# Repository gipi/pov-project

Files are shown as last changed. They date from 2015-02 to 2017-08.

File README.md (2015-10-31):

If you want to try this project you have to initialize using repo
the dependencies

```
$ mkdir pov && cd pov
$ repo init -u http://github.com/gipi/pov-project.git -b master
$ repo sync
```

Now you have some directory:

 - ``src`` containing the source code
 - ``build`` containing the library and build system for AVR

or you can download seperately the build system (my ``avr_stuffs`` repo)
and use the ``CORE_BUILD_DIR`` variable pointing to it

    $ make -C firmware/ CORE_BUILD_DIR=/path/to/build/system

## Test Accelerometer

    make -C firmware/ADXL345/ -f /opt/avr_stuffs/ciaoduino/Makefile.ciaoduino USER_LIB_PATH=~/Arduino/libraries/  ARDUINO_LIBS="Adafruit_Unified_Sensor Adafruit_ADXL345 Wire"

## Links

 - [Post](http://ao2.it/en/blog/2014/04/16/jmp-rope-theory-and-software) about a similar project
 - [Adafruit's related project](https://github.com/adafruit/Adafruit-MiniPOV4-Kit)
 - [Adafruit's very similar project](https://learn.adafruit.com/spokepov/)

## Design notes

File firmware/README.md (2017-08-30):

This directory contains the code to burn in this board as bootloader, it depends
on [LUFA](http://fourwalledcubicle.com/LUFA.php) version 140928.

In order to program with the bootloader you have to ``RESET`` the board while holding
the ``BOOT`` button.
After that the device will alternate on/off the first two leds of the board. 

## Bootloader

There is an extracted tree from the Sparfun's Atmega32u4 breakout (original repository
is [here](https://github.com/sparkfun/32U4_Breakout_Board/tree/master/Bootloaders)).

It's possible to build passing the path to the ``LUFA`` library path, like

    $ make LUFA_PATH=/opt/LUFA-140928/LUFA

(the command must be issued into the ``bootloader/CDC/`` directory). After
the ``hex`` file are generated you can upload with

    $ avrdude -c buspirate -p atmega32u4 -P /dev/ttyUSB0 -b 115200 -F -U flash:w:bootloaders/CDC/BootloaderCDC.hex

The bootloader is capable of emulating a ``avr109`` protocol and you can flash a file
with

    $ avrdude -c avr109 -p atmega32u4 -P /dev/ttyACM0 -F -U flash:w:path/to/file.hex

It's possible to use the arduino IDE with the following ``boards.txt`` entries

```
ciaoduino.name=CiaoDuino
ciaoduino.vid.0=0x2341
ciaoduino.pid.0=0x0036
ciaoduino.vid.1=0x2341
ciaoduino.pid.1=0x8036
ciaoduino.vid.2=0x2A03
ciaoduino.pid.2=0x0036
ciaoduino.vid.3=0x2A03
ciaoduino.pid.3=0x8036

ciaoduino.upload.tool=avrdude
ciaoduino.upload.protocol=avr109
ciaoduino.upload.maximum_size=28672
ciaoduino.upload.maximum_data_size=2560
ciaoduino.upload.speed=57600
ciaoduino.upload.disable_flushing=true
ciaoduino.upload.use_1200bps_touch=true
ciaoduino.upload.wait_for_upload_port=true

ciaoduino.build.mcu=atmega32u4
ciaoduino.build.f_cpu=16000000L
ciaoduino.build.vid=0x2341
ciaoduino.build.pid=0x8036
ciaoduino.build.usb_product="Arduino Leonardo"
ciaoduino.build.board=AVR_LEONARDO
ciaoduino.build.core=arduino
ciaoduino.build.variant=leonardo
ciaoduino.build.extra_flags={build.usb_flags}
```

(we don't know what is strictly necessary) to flash directly into this board. Probably
a manual ``RESET`` is necessary.

## Fuses

You have to set your fuse so that the ``HWBE`` is enabled but not ``BOOT RESET``
(we want the bootloader to be loaded only with the boot button).

A working fuses configuration is obtained with the following command

    $ avrdude -c buspirate -p atmega32u4 -P /dev/ttyUSB0 -b 115200 -U lfuse:w:0xce:m -U hfuse:w:0x99:m -U efuse:w:0xc3:m

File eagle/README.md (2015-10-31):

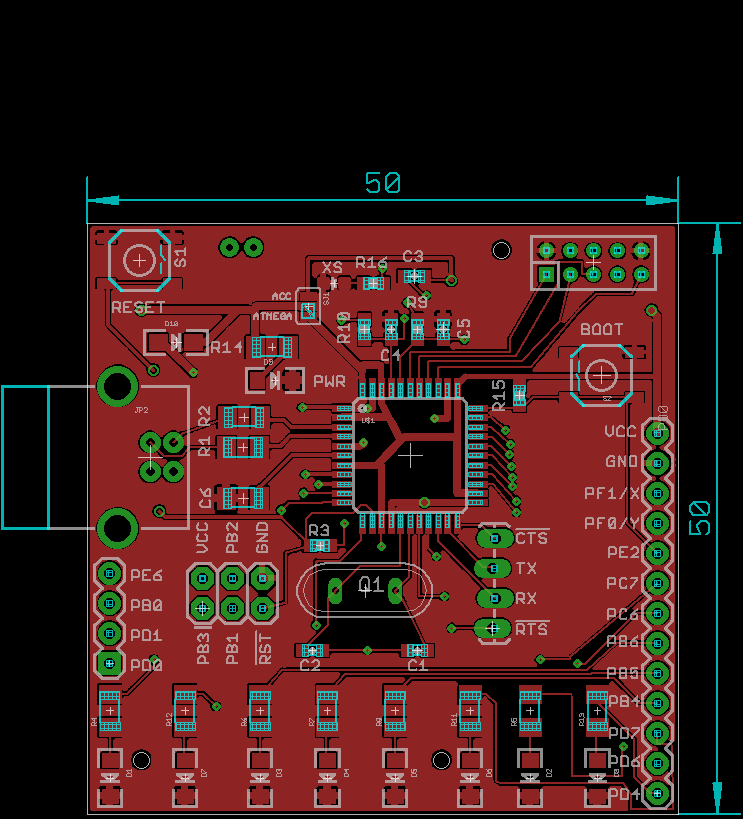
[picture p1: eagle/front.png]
top board layout

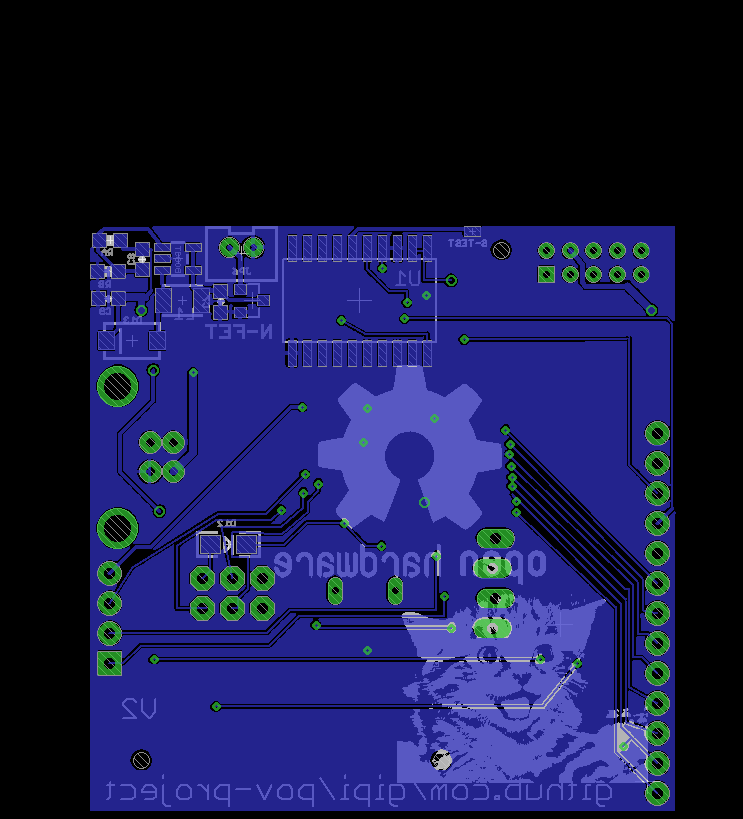
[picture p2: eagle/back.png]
bottom board layout


The ``SJ1`` is a solder-jump that decides which chips  must be powered: the central
pad is the power supply, the left pad is connected to the ``VCC`` of the ``ATMega32U4``
and the right one is connected to the ``VCC`` of the accelerometer. In this way is possible
to test separately these two ICs.

## TODO

 - move power-on led on the other side of the board so to not interfere with POV leds
 - add button to activate device
 - differentiate power supply between USB and battery (maybe use opamp like arduino boards do)
 - use less power consuming accelerometer (MPU-9255)
 - use sensor that gives absolute angular position
 - calculate energy consumption and minimize it
 - calculate theoretically operations timing (is it possible to read from ADC and displaying a picture reliably?)
 - expose pin for external generic power supply (connect them to the battery so we save some diodes)
 - separate pins for ``SPI``, ``I2C``, ``USART`` with power pins near for each of them in order to facilitate coupling with related devices
 - AVCC must be connected to VCC through a low-pass filter

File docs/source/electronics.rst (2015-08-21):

Electronics
===========

Microcontroller
---------------

We are using a ``ATMega32U4`` that has 16MHz clock and a timer with 8-bits resolution
and two available ADC channels with 10 bits resolution.

Accelerometer
-------------

In our solution we used the IC named ``MMA3202KEG``, that has two axis
with 100g and 50g of resolution. It's a linear accelerometer.

Soldering
---------

 #. ATmega32U4
 #. ICPS header
 #. the crystal and the related capacitors
 #. the diode connecyting ISP header with IC
 #. test the programmer sees the device
 #. reset button and reset resistor
 #. the passive part near the USB connector
 #. the USB connector
 #. solder the bridge to supply power to the IC
 #. test if the bootloader is accessible
 #. leds
 #. accelerometer

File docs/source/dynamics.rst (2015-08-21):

Dynamics
--------

Here we introduce the mathematics behind the calculation of the timing of the
led generated patterns: in order to calculate the timing we will using an
accelerometer; other systems(?) use a magnetic sensor to know the device
position and velocity but we don't like this solution since need to have a
magnet hanging on the bike itself.

Let :math:`\omega` be the angular velocity of the wheel, and :math:`R` the
external radius of the wheel and :math:`r` the distance from the center of
the wheel and the accelerometer, we have that the velocity of the wheel is given by

.. math::

   V = \omega R

using our test wheel at a velocity of
:math:`V = 18 km/h = {1.8\cdot 10^{4}\over 3600} m/s=5 m/s`
(using the average speed as indicated by `Wikipedia <https://en.wikipedia.org/wiki/Bicycle_performance#Typical_speeds>`_)
we obtain

.. math::

   \omega = {5 m/s\over 330\cdot 10^{-3}m} = 15.15 rad\cdot s^{-1} \qquad\hbox{i.e.}\quad
   f = {\omega\over 2\pi} = 2.41Hz

Since the centrifugal acceleration is

.. math::

   a = \omega^2\cdot r

we have that our test acceleration is

.. math::

   a = \left(15.15\cdot s^{-1}\right)^2\cdot 333\cdot 10^{-3} m = 76.43 m/s^2 \approx 8g

We need to know the angular velocity of the wheel in order to fit the timing
of the leds for the pattern to be displayed.

The accelerometer is moving together with the wheel and it's so placed in a not inertial
frame, experiencing a costant fictious acceleration along a fixed axes :math:`A` (we call the
axis :math:`A` and :math:`B` to avoid confusion with existing axis in the real device) and
a rotating acceleration with angular velocity :math:`\omega` and fixed magnitude :math:`g`.

When the accelerometer is at angle :math:`\theta` with respect to the vertical the
accelerations measured are

.. math::

    \begin{align}
    a_A &= a_0 + g\cdot\sin \theta\cr
    a_B &= g\cdot\cos\theta\cr
    \end{align}

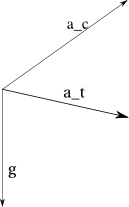
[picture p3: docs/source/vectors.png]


This allows us to calculate the accelerometer angular position from the second equation,
using it in the first to retrieve the angular acceleration and finally compute the angular
velocity (actually the angular position is determined knowning if also the slope of variation
of acceleration otherwise there are two solutions). 

An accelerometer will show reading like this

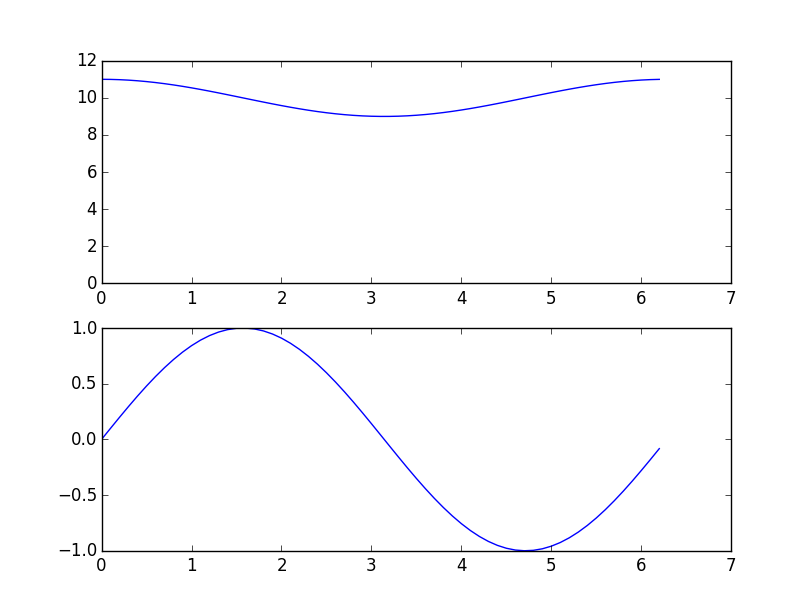
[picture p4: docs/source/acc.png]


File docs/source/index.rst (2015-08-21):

.. POV documentation master file, created by
   sphinx-quickstart on Sat Feb 28 12:23:53 2015.
   You can adapt this file completely to your liking, but it should at least
   contain the root `toctree` directive.

Welcome to POV's documentation!
===============================

The project's aim is to develop a device that display, using the principles
of the **persistence of view**, a pattern on a spinning wheel (a bicycle one).

It utilizes an ``ATMega32U4`` as central processing unit and an accelerometer as
extenal sensor to calibrate internally the position and velocity of the device.

.. toctree::
   :maxdepth: 1

   wheel
   dynamics
   pattern
   electronics
   supply

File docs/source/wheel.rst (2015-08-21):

Wheel
=====

The geometry of the wheel is obviously circular, from `Wikipedia <https://en.wikipedia.org/wiki/Bicycle_wheel#Sizes>`_ we know that
the denomination of the wheels has the pattern::

    <width inflated tire>-<rim's inner width>

In our test we used one with designation ``22-622`` so that the radius of the wheel is 330mm

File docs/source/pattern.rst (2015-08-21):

Pattern
=======

The main aim of this device is to display some pattern during the
wheel rotation, in this section we want to calculate some essential
parameters needed to accomplish that.

We have

 - :math:`f_R` the frequency of rotation of the wheel, we suppose :math:`1\leq f_R\leq 100`
 - :math:`N` the number of the *points* available on the wheel
 - :math:`f_P` the updating frequency of the pattern, :math:`N\leq f_P\leq 100\cdot N`

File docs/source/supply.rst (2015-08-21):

Power Supply
============

There are two main ways to furnish current to the board

 #. USB: it's intended only for programming
 #. a battery connected to the connector ``JP6``: it's the standard way

Probably will be used a LiPo battery with a voltage of 3.7 volts that
will be connected to a boost converter by the ``JP6`` connector;
the core of the DC-DC converter is the ``TPS6104x`` IC.

.. math::

   I_P = 400\hbox{mA} + {V_I\over L} \cdot 100 \hbox{ns}

.. math::

   f_{S_{max}} = {V_{I_{min}}\cdot\left(V_O - V_I\right)\over I_P\cdot L \cdot V_O}

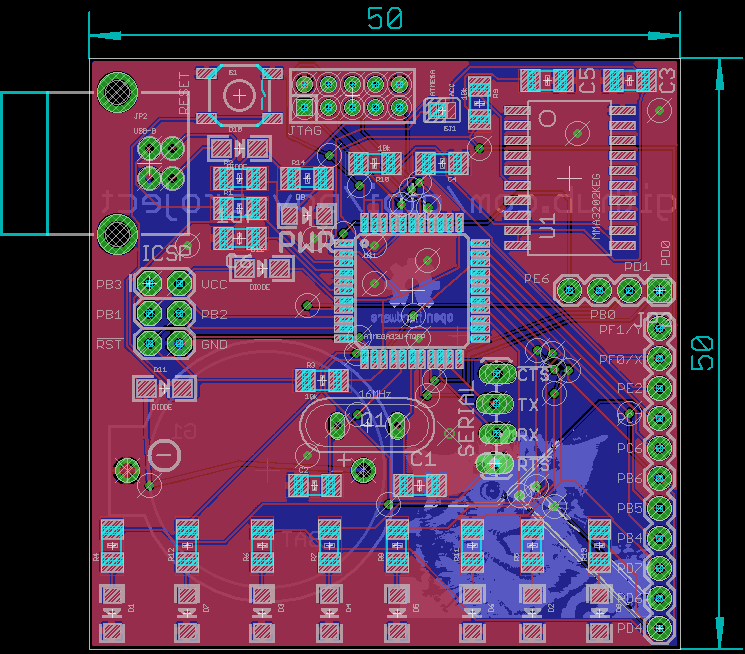
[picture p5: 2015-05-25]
eagle/board.png

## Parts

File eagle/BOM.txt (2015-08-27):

Partlist

Exported from untitled.brd at 27/08/15 13:42

EAGLE Version 7.2.0 Copyright (c) 1988-2014 CadSoft

Assembly variant: 

Part     Value                   Package                   Library               Position (mil)        Orientation

BOOST    TPS61040                SOT23-5                   SparkFun-PowerIC      (321.72699 2970.60593) MR90
C1       22pF                    0603-CAP                  SparkFun-Capacitors   (1120 1665)           R0
C2       22pF                    0603-CAP                  SparkFun-Capacitors   (770 1665)            R180
C3       0.1uF                   0603-CAP                  SparkFun-Capacitors   (1108.91093 2912.87611) R0
C4       10nF                    0603-CAP                  SparkFun-Capacitors   (1032.42901 2735.32406) R270
C5       10nF                    0603-CAP                  SparkFun-Capacitors   (1205.85212 2735.25394) R270
C6       1uf                     C1206                     eagle-ltspice         (538.33698 2173.27005) R180
C7       10nF                    0603-CAP                  SparkFun-Capacitors   (463.42224 2827.24373) MR90
C8       10nF                    0603-CAP                  SparkFun-Capacitors   (201.70325 2967.27202) MR90
C9       10nF                    0603-CAP                  SparkFun-Capacitors   (90.0139 2837.24582)  MR180
D1                               LED-1206                  SparkFun-LED          (95 1240)             R270
D2                               LED-1206                  SparkFun-LED          (1495 1240)           R270
D3                               LED-1206                  SparkFun-LED          (595 1240)            R270
D4                               LED-1206                  SparkFun-LED          (820 1240)            R270
D5                               LED-1206                  SparkFun-LED          (1045 1240)           R270
D6                               LED-1206                  SparkFun-LED          (1295 1240)           R270
D7                               LED-1206                  SparkFun-LED          (345 1240)            R270
D8                               LED-1206                  SparkFun-LED          (1720 1240)           R270
D9                               LED-1206                  SparkFun-LED          (645 2565)            R0
D10      DIODE                   1206                      gipi                  (314.97896 2691.66708) R0
D12      DIODE                   1206                      gipi                  (489.97896 2018.25898) MR180
D13      MBRA140                 SMA-DIODE                 SparkFun-DiscreteSemi (168.3627 2697.21789) MR0
J1       JTAG                    DIL-2MM-2X05              con-headers-jp        (1707.18701 2957.86503) R0
JP1      M13                     1X13                      SparkFun-Connectors   (1920 1190)           R90
JP2      USB-B                   USB-B-PTH                 SparkFun-Connectors   (228.33501 2309.914)  R0
JP3                              1X04                      SparkFun-Connectors   (94.63497 1623.195)   R90
JP4      SERIAL                  1X04_LOCK_LONGPADS        SparkFun-Connectors   (1370 1740)           R90
JP5      ICSP                    2X3                       SparkFun-Connectors   (403.89001 1805.33305) R0
JP6      M02JST-PTH-VERT         JST-2-PTH-VERT            SparkFun-Connectors   (533.43602 2987.27608) MR180
L1       3.3uH                   1210                      SparkFun-Passives     (335.72822 2832.25135) MR0
N-FET    N-CHANNEL-MOSFET-BSS138 SOT23-3                   GeekAmmo              (568.44291 2830.578)  MR90
Q1       16MHz                   QS                        special               (945 1865)            R180
R1       22                      1206                      SparkFun-Passives     (538.33686 2341.617)  R0
R2       22                      1206                      SparkFun-Passives     (541.67114 2443.28383) R0
R3       10k                     0603-RES                  SparkFun-Passives     (795 2015)            R0
R4                               1206                      SparkFun-Passives     (95 1465)             R90
R5                               1206                      SparkFun-Passives     (1495 1465)           R90
R6                               1206                      SparkFun-Passives     (595 1465)            R90
R7                               1206                      SparkFun-Passives     (820 1465)            R90
R8                               1206                      SparkFun-Passives     (1045 1465)           R90
R9       1k                      0603-RES                  SparkFun-Passives     (1118.81312 2734.49176) R270
R10      1k                      0603-RES                  SparkFun-Passives     (944.078 2735.36897)  R270
R11                              1206                      SparkFun-Passives     (1295 1465)           R90
R12                              1206                      SparkFun-Passives     (345 1465)            R90
R13                              1206                      SparkFun-Passives     (1720 1465)           R90
R14      1k                      1206                      SparkFun-Passives     (634.97798 2676.664)  R0
R15      10k                     0603-RES                  SparkFun-Passives     (1461.195 2517.00209) R90
R16      1k                      0603-RES                  SparkFun-Passives     (973.52399 2888.92298) R180
RA       3.09k                   0603-RES                  SparkFun-Passives     (95.01698 3032.28322) MR180
RB       1k                      0603-RES                  SparkFun-Passives     (88.34707 2928.93086) MR180
S1       RESET                   TACTILE-SWITCH-SMD        SparkFun-Retired      (193.26809 2965)      R0
S2       BOOT                    TACTILE-SWITCH-SMD        SparkFun-Retired      (1733.66781 2583.75898) R180
SJ1                              SJ_3_PASTE2&3             SparkFun-Retired      (757.40908 2812.00591) R270
TP1      TESTPAD                 TP_SEMICIRCULAR           gipi                  (1302 3062)           MR0
U$1      ATMEGA32U4TQFP          SPARKFUN-DIGITALIC_TQFP44 SparkFun-Retired      (1095 2315)           R0
U1       MMA3202KEG              SOIC20                    gipi                  (927.96494 2830.89801) MR270
XS                               LED-0603                  SparkFun-LED          (841.83108 2888.92298) R90

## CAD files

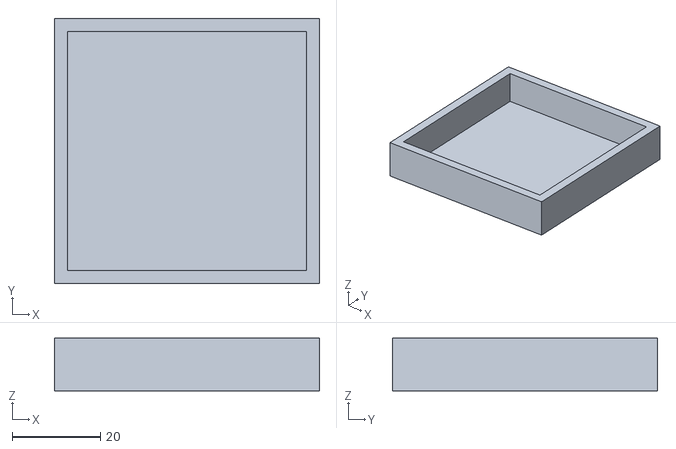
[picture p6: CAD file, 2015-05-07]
eagle/pov.stl
60.0 x 60.0 x 12.0

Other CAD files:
eagle/pov.blend

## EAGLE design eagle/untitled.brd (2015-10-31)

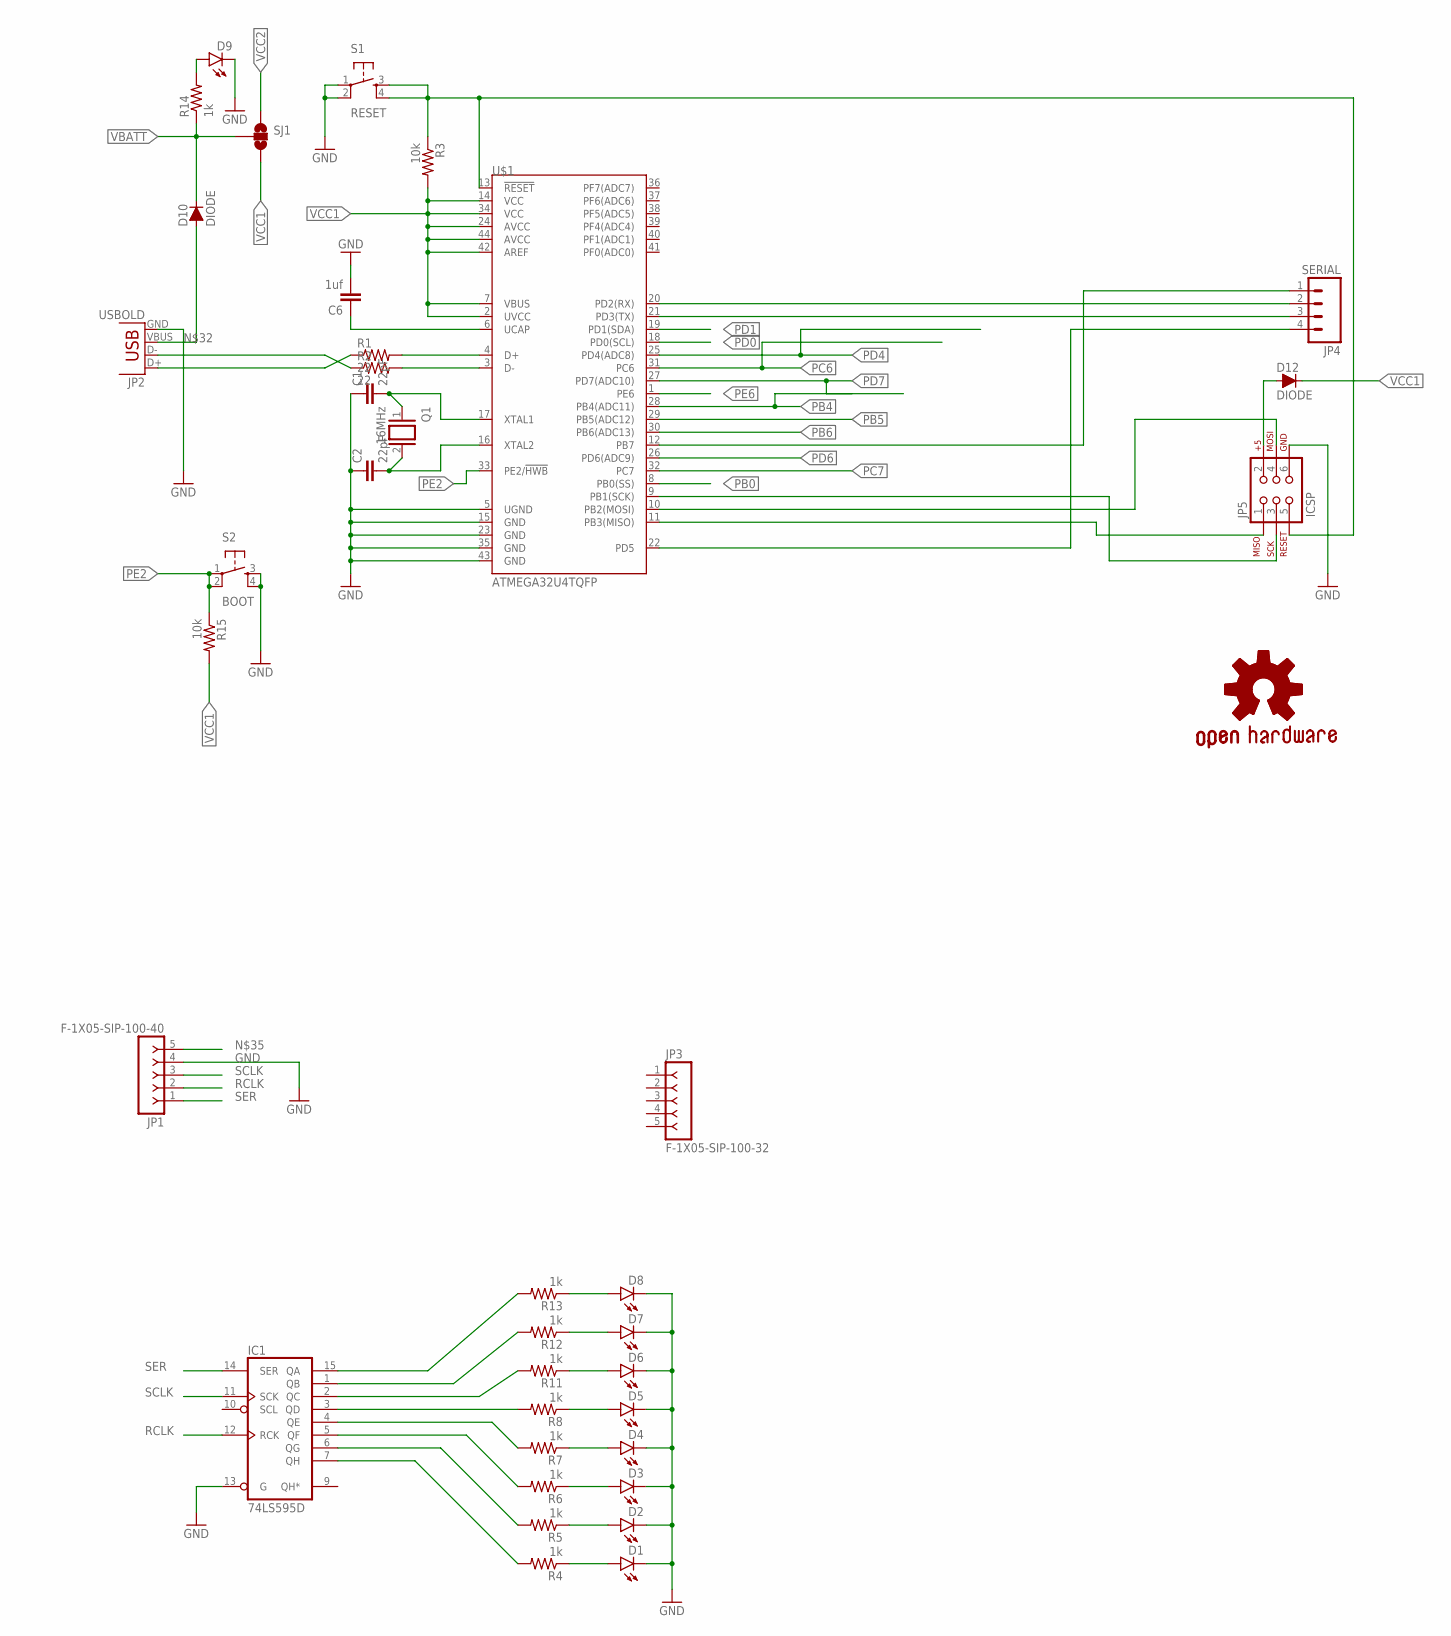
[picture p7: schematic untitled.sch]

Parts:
C1, C2: 22pF; 0603-CAP
C6: 1uf; C0603
D1, D2, D3, D4, D5, D6, D7, D8, D9: LED1206; LED-1206
D10, D12: DIODE; 1206
GOLD_ORB_SM1: OSHWLOGO_GOLD_ORB_LG; OSHW0
IC1: 74LS595D; SO16
JP1: F-1X05-SIP-100-40; SIP-100-05-40
JP2: USBOLD; USB-MINIB-OLD
JP3: F-1X05-SIP-100-32; SIP-100-05-32
JP4: SERIAL; 1X04_LOCK_LONGPADS
JP5: ICSP; 2X3
Q1: 16MHz; QS
R1, R2: 22; 0603-RES
R3, R15: 10k; 0603-RES
R4, R5, R6, R7, R8, R11, R12, R13: 1k; 0603-RES
R14: 1k; 1206
S1: RESET; TACTILE-SWITCH-SMD
S2: BOOT; TACTILE-SWITCH-SMD
SJ1: SOLDERJUMPER_2WAYPASTE2&3; SJ_3_PASTE2&3
U$1: ATMEGA32U4TQFP; SPARKFUN-DIGITALIC_TQFP44

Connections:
GND: C1.1, C2.1, C6.2, D1.C, D2.C, D3.C, D4.C, D5.C, D6.C, D7.C, D8.C, D9.C, IC1.8 (GND), IC1.13 (G), JP1.4, JP2.GND, JP5.6, S1.1, S1.2, S2.3, S2.4, U$1.5 (UGND), U$1.15 (GND), U$1.23 (GND), U$1.35 (GND), U$1.43 (GND)
unnamed: IC1.15 (QA), R13.2
unnamed: D1.A, R4.1
unnamed: JP2.D-, R2.1
unnamed: JP2.D+, R1.1
unnamed: R1.2, U$1.4 (D+)
unnamed: R2.2, U$1.3 (D-)
unnamed: D2.A, R5.1
unnamed: D3.A, R6.1
unnamed: D4.A, R7.1
unnamed: D5.A, R8.1
unnamed: JP5.1, U$1.11 (PB3(MISO))
unnamed: JP5.3, U$1.9 (PB1(SCK))
unnamed: JP5.4, U$1.10 (PB2(MOSI))
unnamed: D6.A, R11.1
unnamed: D7.A, R12.1
unnamed: C1.2, Q1.1, U$1.17 (XTAL1)
unnamed: JP5.5, R3.1, S1.3, S1.4, U$1.13 (!RESET)
unnamed: D9.A, R14.2
unnamed: C2.2, Q1.2, U$1.16 (XTAL2)
unnamed: D8.A, R13.1
unnamed: IC1.1 (QB), R12.2
unnamed: IC1.2 (QC), R11.2
unnamed: C6.1, U$1.6 (UCAP)
unnamed: JP4.4, U$1.22 (PD5)
unnamed: IC1.3 (QD), R8.2
unnamed: IC1.4 (QE), R7.2
unnamed: IC1.5 (QF), R6.2
unnamed: IC1.6 (QG), R5.2
unnamed: JP4.2, U$1.20 (PD2(RX))
unnamed: JP4.3, U$1.21 (PD3(TX))
unnamed: D10.P$1 (A), JP2.VBUS
unnamed: IC1.7 (QH), R4.2
unnamed: D12.P$1 (A), JP5.2
PB0: U$1.8 (PB0(SS))
PB4: U$1.28 (PB4(ADC11))
PB5: U$1.29 (PB5(ADC12))
PB6: U$1.30 (PB6(ADC13))
PB7: JP4.1, U$1.12 (PB7)
PC6: U$1.31 (PC6)
PC7: U$1.32 (PC7)
PD0: U$1.18 (PD0(SCL))
PD1: U$1.19 (PD1(SDA))
PD4: U$1.25 (PD4(ADC8))
PD6: U$1.26 (PD6(ADC9))
PD7: U$1.27 (PD7(ADC10))
PE2: R15.1, S2.1, S2.2, U$1.33 (PE2/!HWB)
PE6: U$1.1 (PE6)
RCLK: IC1.12 (RCK), JP1.2
SCLK: IC1.11 (SCK), JP1.3
SER: IC1.14 (SER), JP1.1
VBATT: D10.P$2 (C), R14.1, SJ1.2
VCC: IC1.16 (VCC)
VCC1: D12.P$2 (C), R3.2, R15.2, SJ1.3, U$1.2 (UVCC), U$1.7 (VBUS), U$1.14 (VCC), U$1.24 (AVCC), U$1.34 (VCC), U$1.42 (AREF), U$1.44 (AVCC)
VCC2: SJ1.1

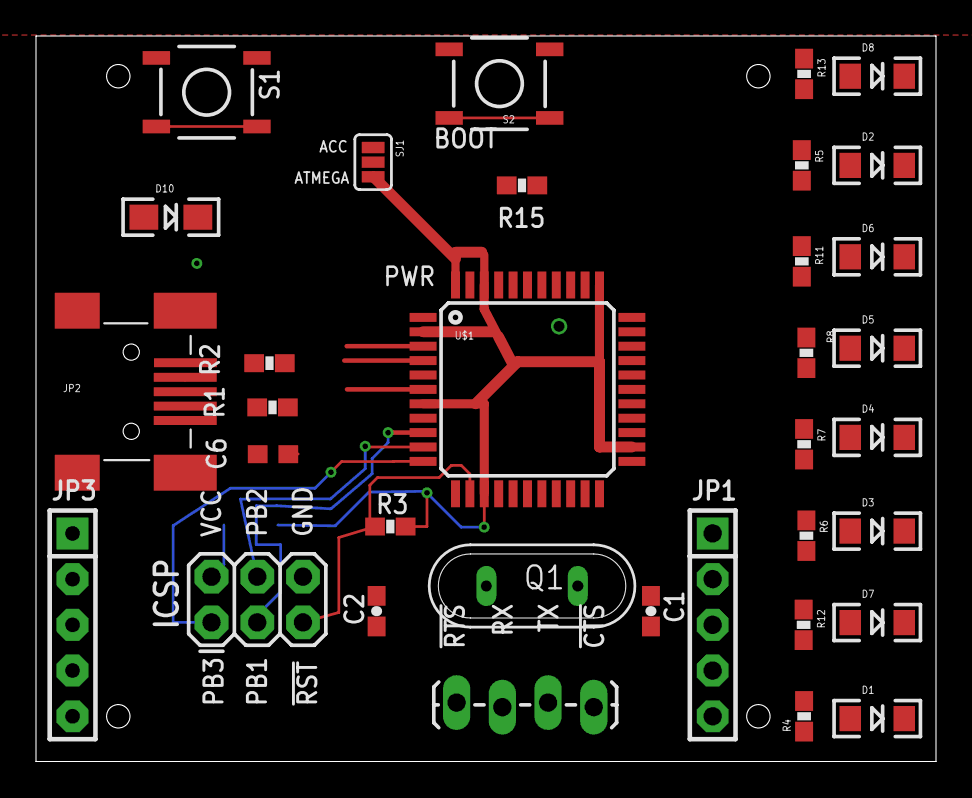
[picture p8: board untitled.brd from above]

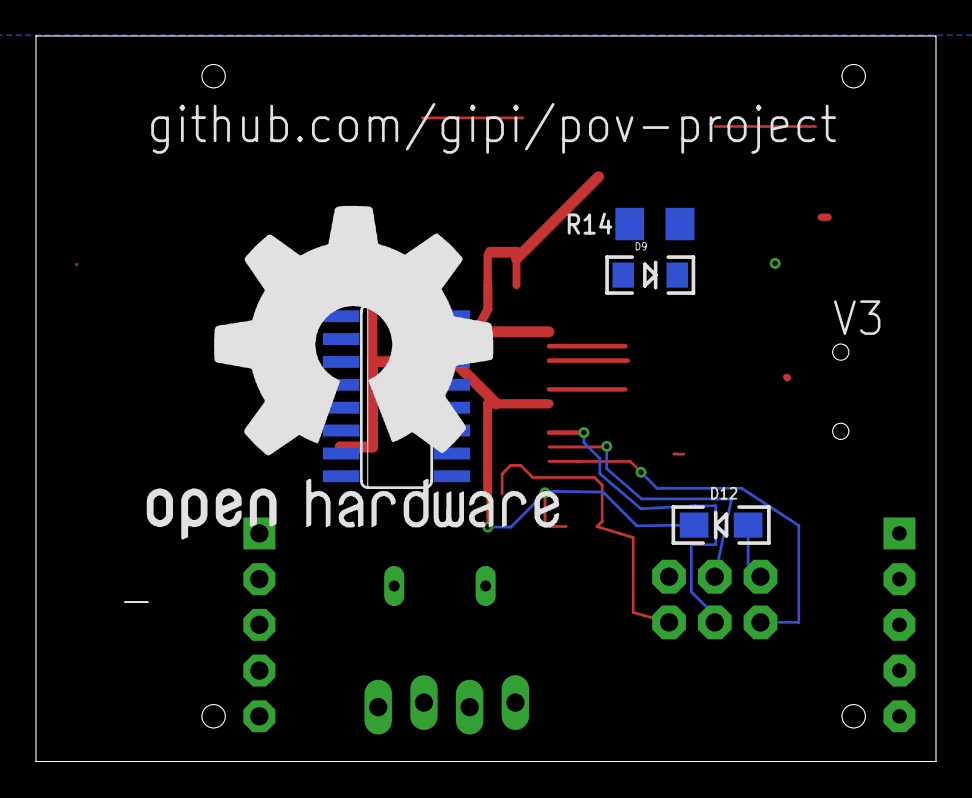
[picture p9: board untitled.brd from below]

Board: 2 copper layers, 50.0 x 40.3 mm, 39 parts (5 on the bottom side), 41 nets.

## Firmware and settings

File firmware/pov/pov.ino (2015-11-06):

/*
 * Firmware of the Persistence of View (POV) circuitery.
 *
 * The IC will be an Atmega32U4.
 *
 * TODO:
 *  - load patterns by UART and save in the EEPROM
 *  - allow for more "depth" of patterns (monochrome, RGB)
 *  - animations
 */

#include <avr/power.h>
#include <avr/interrupt.h>
#include <util/delay.h>
#include <Wire.h>
#include <EEPROM.h>
#include <Adafruit_Sensor.h>
#include <Adafruit_ADXL345_U.h>

#include "log.h"
#include "timing.h"
#include "leds.h"

// define __DUMP__ only if you want to save into the EEPROM
// the value read. Note that the EEPROM has only a finite number
// of erase/write operation so be wise with this option.
#ifdef __DUMP__
#include "dump.h"
#endif //__DUMP__

sensors_event_t event; 

// set as output all the leds

// DO NOT INITIALIZE HERE OTHERWISE FAIL
// SINCE (?) CONSTRUCTOR IS CALLED BEFORE MAIN()
/* Assign a unique ID to this sensor at the same time */
Adafruit_ADXL345_Unified accel = Adafruit_ADXL345_Unified(12345);

/************* EEPROM **********************/
#ifdef __DUMP__
void dump_acc_history() {
    logme();
}
#endif

void update_acc_register() {
#ifdef __DUMP__
    // we need signed (maybe use abs())
    int8_t actual_x_value = event.acceleration.x;

    if (actual_x_value < acc_history.min ) {
        acc_history.min = actual_x_value;
    }
    if (actual_x_value > acc_history.max ) {
        acc_history.max = actual_x_value;
    }

#warning "EEPROM writing enabled"
    // save the data into the eeprom
    EEPROM.write(0, acc_history.min);
    EEPROM.write(1, acc_history.max);
    EEPROM.write(2 + acc_history.idx, actual_x_value);

    // update the index (1024 is the EEPROM size in the ATMEGA32U4)
    acc_history.idx = (acc_history.idx + 1) % (1024 - 2);
#endif //__DUMP__
}

struct state_t* state = NULL;

void calibrate_timing() {
    int8_t actual_x_value = event.acceleration.x;
    int8_t actual_y_value = event.acceleration.y;

    update_state(&state, actual_x_value, actual_y_value);
}

void timer1_ovf_callback() {
    calibrate_timing();

    logme("x=%hhd y=%hhd", state->x_value, state->y_value);

    //if (state->x_extreme != UNDEFINED || state->y_extreme != UNDEFINED)
    if (state->x_extreme != UNDEFINED) {
        set_led_on(0);
        _delay_ms(2);
        set_led_off(0);
        //display_next();
    }

    update_acc_register();
}

ISR(TIMER1_OVF_vect) {
    timer1_ovf_callback();

    TCNT1 = 0;
}

/**
 * The Timer1 is a 16bits counter.
 *
 * An overflow at 16MHz without prescaler is given by
 *
 *  16000000/65536 = 244.14Hz
 *
 * (We are not using the Timer0 counter since is used by Wire, maybe)
 */
void init_timer() {
    logme("init_timer()");

    cli();

    TCCR1A = 0;
    TCNT1 = 0;
    TCCR1B |= _BV(CS10); // without prescaler
    TCCR1B &= ~_BV(CS11);
    TCCR1B &= ~_BV(CS12);
    TIMSK1 |= _BV(TOIE1);            // enable Timer1 Overflow Interrupt

    sei();
}

void setup() {
    loginit();

    logme("src:%s", __FILE__);

    logme("setup()");

    init_led_system();

    led_self_test();

    if(!accel.begin()){
        while(1)
            logme("No ADXL345!! check your wiring please.");
    }
    /* Set the range to whatever is appropriate for your project */
    accel.setRange(ADXL345_RANGE_16_G);

    //init_timer();
}

void loop() {
    logme("loop()");
    while(1) {
        /* Get a new sensor event */ 
        accel.getEvent(&event);
        timer1_ovf_callback();
    }
}

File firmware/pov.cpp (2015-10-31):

/*
 * Firmware of the Persistence of View (POV) circuitery.
 *
 * The IC will be an Atmega32U4.
 *
 * TODO:
 *  - load patterns by UART and save in the EEPROM
 *  - allow for more "depth" of patterns (monochrome, RGB)
 *  - animations
 */
#include <avr/io.h>
#include <avr/power.h>
#include <avr/interrupt.h>
#include <util/delay.h>
#ifdef __AXX__
#include <Wire.h>
#include <EEPROM.h>
#include <Adafruit_Sensor.h>
#include <Adafruit_ADXL345_U.h>
#endif

//#define TEST


/*
 * From "making a glyph from bit patterns" chapter of "Expert C
 * programming" by Peter Van Der Linden.
 *
 * The variable named "pattern" contains the bits pattern to be
 * used for our POV firmware. Using these #defines we can present
 * the programmer with a very immediate way to understand it.
 */
#define X )*2+1
#define _ )*2
#define s ((((((((0 /* For building pattern 8 bit wide */

const static unsigned char pattern[] = {
#if 0
    s _ _ _ X X _ _ _,
    s _ _ X X X X _ _,
    s _ X X X X X X _,
    s X X X X X X X X,
    s _ _ X X X X _ _,
    s _ _ X X X X _ _,
    s _ _ X X X X _ _,
    s _ _ X X X X _ _,
#else
    s X _ _ _ _ _ _ _,
    s _ X _ _ _ _ _ _,
    s _ _ X _ _ _ _ _,
    s _ _ _ X _ _ _ _,
    s _ _ _ _ X _ _ _,
    s _ _ _ _ _ X _ _,
    s _ _ _ _ _ _ X _,
    s _ _ _ _ _ _ _ X,
    s _ _ _ _ _ _ X _,
    s _ _ _ _ _ X _ _,
    s _ _ _ _ X _ _ _,
    s _ _ _ X _ _ _ _,
    s _ _ X _ _ _ _ _,
    s _ X _ _ _ _ _ _,
#endif
};

#undef X
#undef _
#undef s

#define DELAY_QUICK_VALUE 100
#define DELAY_VALUE 1000

// http://www.nongnu.org/avr-libc/user-manual/FAQ.html#faq_port_pass
struct led_t {
    volatile uint8_t   *ddm;
    unsigned int short dd;
    volatile uint8_t   *portm;
    unsigned int short port;
};

struct led_t leds[] = {
    {.ddm = &DDRC, .dd = DDC7, .portm = &PORTC, .port = PORTC7},
    {.ddm = &DDRC, .dd = DDC6, .portm = &PORTC, .port = PORTC6},
    {.ddm = &DDRB, .dd = DDB6, .portm = &PORTB, .port = PORTB6},
    {.ddm = &DDRB, .dd = DDB5, .portm = &PORTB, .port = PORTB5},
    {.ddm = &DDRB, .dd = DDB4, .portm = &PORTB, .port = PORTB4},
    {.ddm = &DDRD, .dd = DDD7, .portm = &PORTD, .port = PORTD7},
    {.ddm = &DDRD, .dd = DDD6, .portm = &PORTD, .port = PORTD6},
    {.ddm = &DDRD, .dd = DDD4, .portm = &PORTD, .port = PORTD4},
};

// set as output all the leds
void init_led_system() {
    unsigned int idx = 0;

    for (idx = 0 ; idx < sizeof(leds) ; idx++) {
        struct led_t led = leds[idx];
        *led.ddm |= _BV(led.dd);
    }
}

enum led_state_t {
    ON,
    OFF
};

void set_led(unsigned short idx, enum led_state_t state) {
    struct led_t led = leds[idx];

    switch(state) {
        case ON:
            *led.portm |= _BV(led.port);
            break;
        case OFF:
            *led.portm &= ~_BV(led.port);
            break;
    }
}

void set_led_on (unsigned int idx) {
    set_led(idx, ON);
}

void set_led_off(unsigned int idx) {
    set_led(idx, OFF);
}

/**
 * Simply loop over all the leds
 */
void led_self_test() {
    unsigned int idx;

    for (idx = 0 ; idx < sizeof(leds)/sizeof(struct led_t) ; idx++) {
        set_led_on(idx);
        _delay_ms(DELAY_QUICK_VALUE);
    }

    for (idx = 0 ; idx < sizeof(leds)/sizeof(struct led_t) ; idx++) {
        set_led_off(idx);
        _delay_ms(DELAY_QUICK_VALUE);
    }
}

#define GET_STATE(digit,index) (digit & (1 << index)) > 0 ? ON : OFF
void display_bit_pattern(uint8_t digit, uint8_t size) {
    int index;

    for (index = 0 ; index < size ; index++) {
        set_led(index, GET_STATE(digit, index));
    }
}

uint8_t g_index = 0;

void display_next() {
    // display the row
    display_bit_pattern(pattern[g_index++ % sizeof(pattern)], 8);
}

#ifdef __AXX__
/* Assign a unique ID to this sensor at the same time */
Adafruit_ADXL345_Unified accel = Adafruit_ADXL345_Unified(12345);

/************* EEPROM **********************/
/**
 * Register in the EEPROM the accelerometer data.
 */
struct _acc_history {
    uint8_t min;
    uint8_t max;
    uint16_t idx;
} acc_history;

void update_acc_register(sensors_event_t event) {
    uint8_t actual_x_value = event.acceleration.x;
    if (event.acceleration.x < acc_history.min ) {
        acc_history.min = actual_x_value;
    }
    if (event.acceleration.x > acc_history.max ) {
        acc_history.max = actual_x_value;
    }

    // save the data into the eeprom
    EEPROM.write(0, acc_history.min);
    EEPROM.write(1, acc_history.max);
    EEPROM.write(2 + acc_history.idx, actual_x_value);

    // update the index (1024 is the EEPROM size in the ATMEGA32U4)
    acc_history.idx = (acc_history.idx + 1) % (1024 - 2);
}
#endif

/**
 * The Timer1 is a 16bits counter.
 *
 * An overflow at 16MHz without prescaler is given by
 *
 *  16000000/65536 = 244.14Hz
 *
 * (We are not using the Timer0 counter since is used by Wire, maybe)
 */
void init_timer() {
    cli();
   // TCCR1B |= ~_BV(CS12) | ~_BV(CS11) | _BV(CS10);
    TCCR1A = 0;
    TCNT1 = 0;
    TCCR1B |= _BV(CS12) | ~_BV(CS11) | _BV(CS10);
    TIMSK1 |= _BV(TOIE1);            // enable Timer1 Overflow Interrupt

    sei();
}


ISR(TIMER1_OVF_vect) {
    display_next();

#ifdef __AXX__
    /* Get a new sensor event */ 
    sensors_event_t event; 
    accel.getEvent(&event);
    update_acc_register(event);
#endif

    TCNT1 = 0;
}




int main() {
    clock_prescale_set(clock_div_1);

    init_led_system();

    led_self_test();

#ifdef __AXX__
    accel.begin();

    /* Set the range to whatever is appropriate for your project */
    accel.setRange(ADXL345_RANGE_16_G);
#endif
    init_timer();

    while(1)//; // needed in order to avoid crash (maybe?)
    {
#ifdef TEST
        display_next();
        _delay_ms(1000);
#endif
    }

    return 0;
}

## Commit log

2012-11-28 First attempt to do serial connection with an Arduino.
    The tests was done with an echo C AVR program flashed into the Arduino.
2015-05-05 Add eagle files.
    [untitled.brd, untitled.sch]
2015-05-05 Add pin labels.
    [untitled.brd]
2015-05-05 Smash and rework some labels.
    [untitled.brd]
2015-05-05 Update schematics.
    [untitled.sch]
2015-05-07 Add experimental 3D case model.
    [pov.blend, pov.stl]
2015-05-07 Update board image.
2015-05-07 Rework some labels.
    [untitled.sch]
2015-05-17 Replace usb micro connector with mini type.
    [untitled.brd, untitled.sch]
2015-05-24 Update eagle files.
    [untitled.brd, untitled.sch]
2015-05-24 Update board layout.
    [untitled.brd, untitled.sch]
2015-05-25 Update eagle.
    [untitled.brd, untitled.sch]
2015-07-12 Update some component values.
    [untitled.brd, untitled.sch]
2015-07-18 Add section about soldering.
2015-07-19 Rework soldering docs.
2015-07-19 Add missing soldering step.
2015-07-21 Add BOOT button and reroute stuffs.
    [untitled.brd, untitled.sch]
2015-07-22 Name the board(?).
2015-07-22 Modify bootloader code to adapt to this board.
2015-08-14 Fix wrong labelling X/Y.
    [untitled.brd]
2015-08-14 Update board.
    [untitled.brd, untitled.sch]
2015-08-17 Add reverse voltage protection by P-MOSFET + Labelling.
    [untitled.brd, untitled.sch]
2015-08-20 Rework labels.
    [untitled.brd, untitled.sch]
2015-08-20 Fix board layout.
    Done some rerouting.
    [untitled.brd, untitled.sch]
2015-08-21 Use interrupt.
2015-08-21 Move the accelerometer info in its own section.
2015-08-21 Rework some traces.
    [untitled.brd, untitled.sch]
2015-08-24 Modified some trace's widths.
    [untitled.brd]
2015-08-24 Fix label mosfet.
    [untitled.brd, untitled.sch]
2015-08-24 Reroute reset signal.
    [untitled.brd]
2015-08-24 Update BOM.
2015-08-24 Add self test pad for accelerometer.
    [untitled.brd, untitled.sch]
2015-08-27 2nd version in production.
    [untitled.brd, untitled.sch]
2015-10-02 Fix mess with ground.
    [untitled.brd, untitled.sch]
2015-10-31 Timer1 overflow.
2015-10-31 Update ciaoduino's eagle files.
    [untitled.brd, untitled.sch]
2015-11-03 Try without timer.
2015-11-05 Continue to log if the accelerometer is not available.
2016-03-26 Fix bootloader to make it works with Arduino IDE.

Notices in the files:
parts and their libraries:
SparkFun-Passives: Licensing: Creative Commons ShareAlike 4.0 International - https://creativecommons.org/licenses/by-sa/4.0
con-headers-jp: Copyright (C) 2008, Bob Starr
